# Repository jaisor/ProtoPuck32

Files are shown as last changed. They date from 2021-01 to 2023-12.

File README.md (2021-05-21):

# ProtoPuck32

Multi-purpose prototype box based on ESP32

## Development

USB driver for Windows required: [Silicon Labs CP210X](https://www.silabs.com/developers/usb-to-uart-bridge-vcp-drivers)

Recommended: [VSCode](https://code.visualstudio.com/) + [PlatformIO](https://platformio.org/)

## Issues

LittleFS_esp32 library installed by PlatformIO seems broken, complaining about 

```
error: unknown field 'utime_p' specified in initializer
```
Replacing `libdeps/LittleFS_esp32` with downliad from [LittleFS_esp32](https://www.arduinolibraries.info/libraries/little-fs_esp32) fixes it

## Bill of materials (BOM)

* [ESP32 Wroom](https://www.amazon.com/gp/product/B08D5ZD528)
* [OLED 128x64 i2c](https://www.amazon.com/gp/product/B072Q2X2LL)
* [BME280 Temperature/Humidity sendor i2c](https://www.amazon.com/gp/product/B07KYJNFMD)
* [FPV Camera keypad](https://www.amazon.com/RunCam-Key-Board-FPV-Camera/dp/B0874GPT4W) - I used a joystick style from Caddx, but any would work, case will need adjustment
* [DC plug connector](https://www.amazon.com/gp/product/B01N8VV78D)
* [5V 15A power adapter](https://www.amazon.com/gp/product/B08764XJ2M)
* [White PLA for case and LED diffusion](https://www.amazon.com/gp/product/B01EKEMIIS)

---

## Builds

### LED Node Leaf

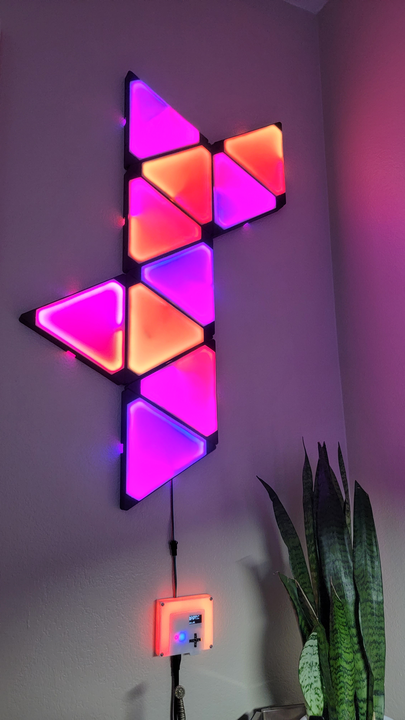
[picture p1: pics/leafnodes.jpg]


Solder the DI/Signal wire (usually middle of the strip) to pin 13, otherwise change the `LED_PIN` in `Configuration.h`

## Bill of materials (BOM)

In addition to the base driver above:
* [WS2812B RGB LED Strip Light](https://www.amazon.com/gp/product/B08B59CBK9/)
* [RGBZONE 20Pairs JST SM 3PIN Plugs](https://www.amazon.com/gp/product/B075K4HLTQ/)

Case - 3D printed, STL files:

* [LED diffuser](case/NodeLeaf/LEDNodeLeafDiffuser.stl)
* [LED frame](case/NodeLeaf/LEDNodeLeafBase.stl)

### LED Matrix

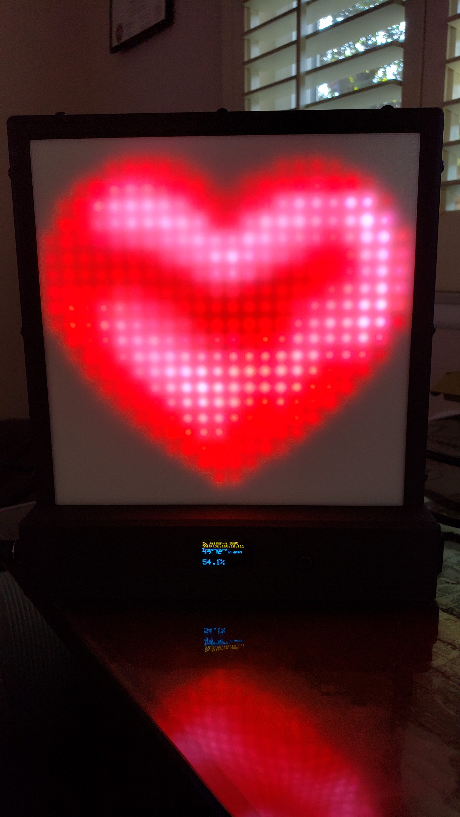
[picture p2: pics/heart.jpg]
LED displaying heart

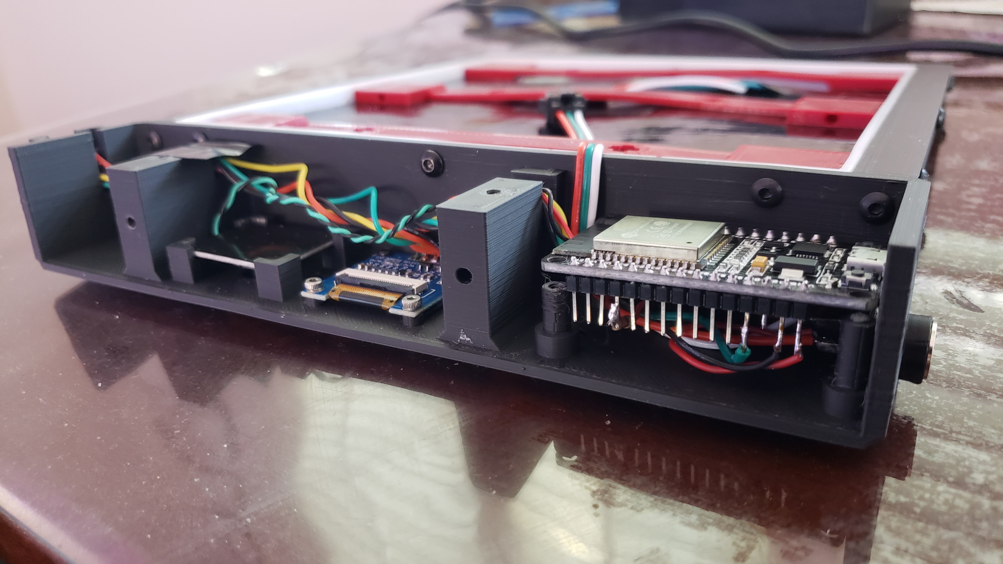
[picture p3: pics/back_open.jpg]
Back-bottom open, shows parts


Add to BOM: [22x22 WS2812B pannel](https://www.amazon.com/gp/product/B075T9RRPM)

Schematic:

Schematic

Case - 3D printed, STL files:

* [LED diffuser](case/LED_Matrix/LEDMatrix-Diffuser.stl)
* [LED frame](case/LED_Matrix/LEDMatrix-FrameSide.stl)
* [LED frame back brace](case/LED_Matrix/LEDMatrix-FrameBackBrace.stl)
* [Base](case/LED_Matrix/LEDMatrix-FrameBase.stl)
* [Base lid](case/LED_Matrix/LEDMatrix-FrameBaseLid.stl)

---

# Bugs / TODO

1. Connecting to Wifi AP after creating one fails - probably something needs to be cleaned up in the WiFi instances
1. Configuration menu
1. Remote controlled pixels via WiFi (HTTP Post or MQTT)
1. Report sensors data and config out to HTTP or MQTT
1. Remote control of config like brightness, mode, etc.
1. Yellow top lines for Config - looks odd
1. Web page headers and titles - remove Demo
1. Get device location automatically if possible
1. Expose current clock broadly, including periodical updates

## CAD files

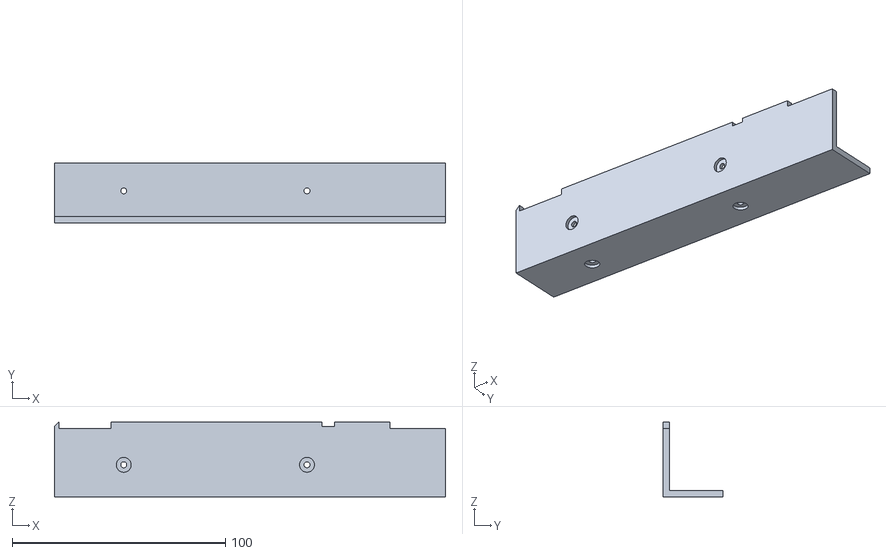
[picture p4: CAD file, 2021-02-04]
case/LED_Matrix/LEDMatrix-FrameBaseLid.stl
183.5 x 28.0 x 35.0

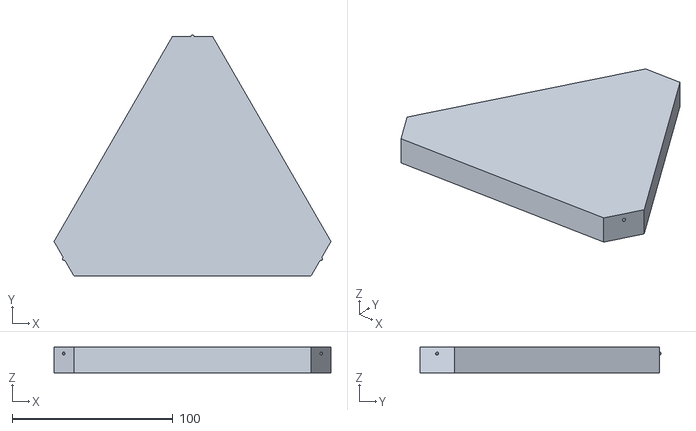
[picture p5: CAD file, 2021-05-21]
case/NodeLeaf/LEDNodeLeafDiffuser.stl
172.5 x 150.3 x 16.0

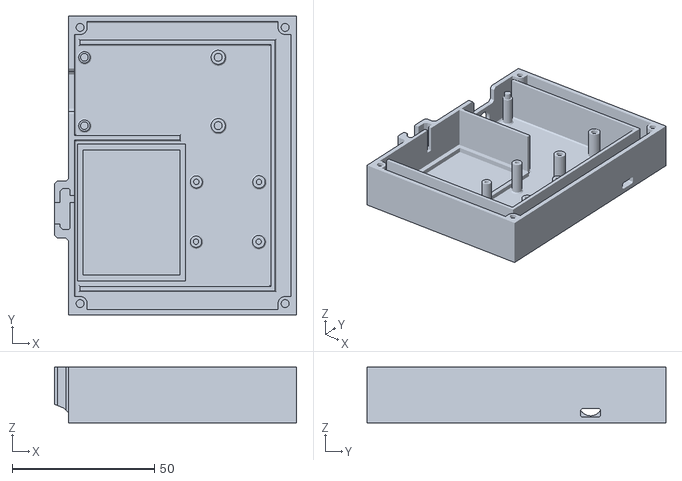
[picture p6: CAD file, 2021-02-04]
case/ProtoPuck32-Case.stl
85.0 x 105.0 x 19.5

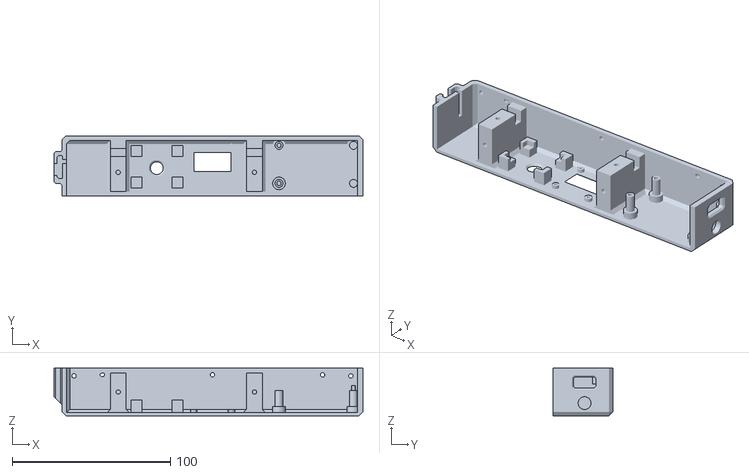
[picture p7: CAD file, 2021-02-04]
case/LED_Matrix/LEDMatrix-FrameBase.stl
195.0 x 38.0 x 30.0

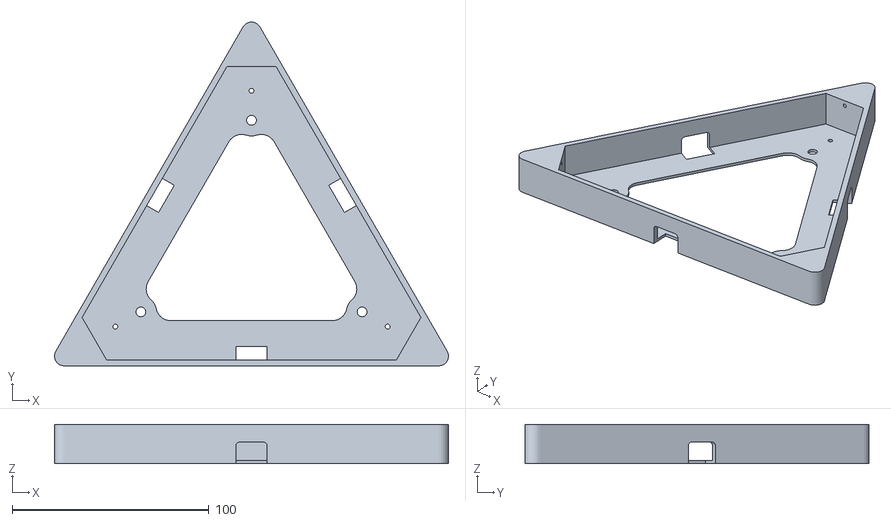
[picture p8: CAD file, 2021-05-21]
case/NodeLeaf/LEDNodeLeafBase.stl
200.5 x 175.0 x 20.0

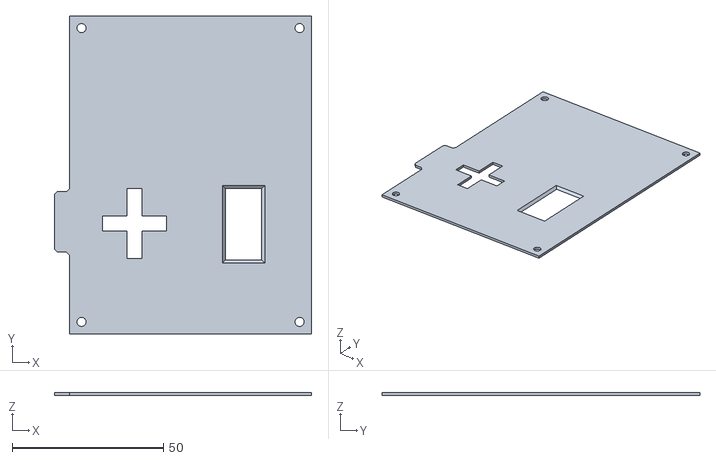
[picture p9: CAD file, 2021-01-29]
case/ProtoPuck32-5ButtonSmall-Lid.stl
85.0 x 105.0 x 1.00

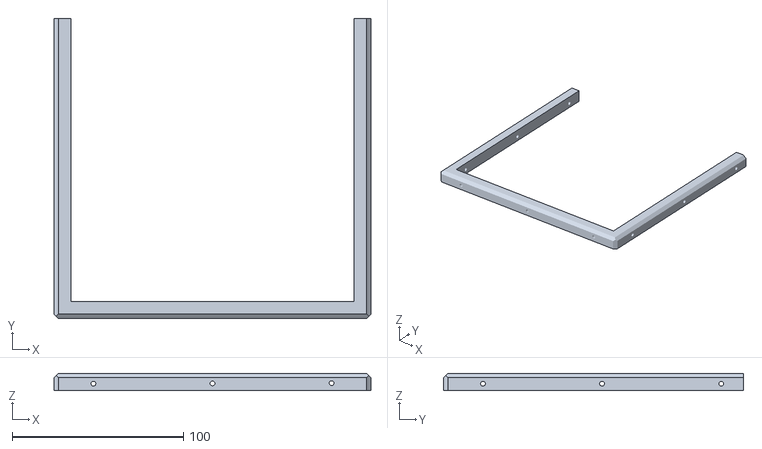
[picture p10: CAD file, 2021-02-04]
case/LED_Matrix/LEDMatrix-FrameSide.stl
185.0 x 175.0 x 10.0

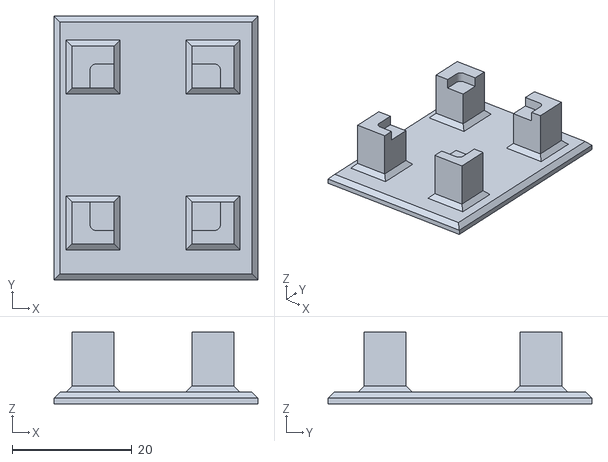
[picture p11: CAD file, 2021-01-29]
case/ProtoPuck32-1Button-Keypad.stl
34.0 x 44.0 x 12.0

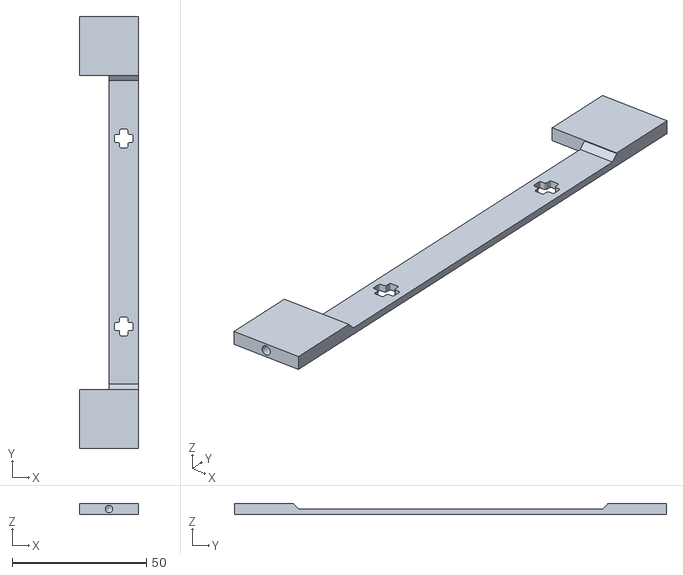
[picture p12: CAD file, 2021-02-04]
case/LED_Matrix/LEDMatrix-FrameBackBrace.stl
22.0 x 161.0 x 4.00

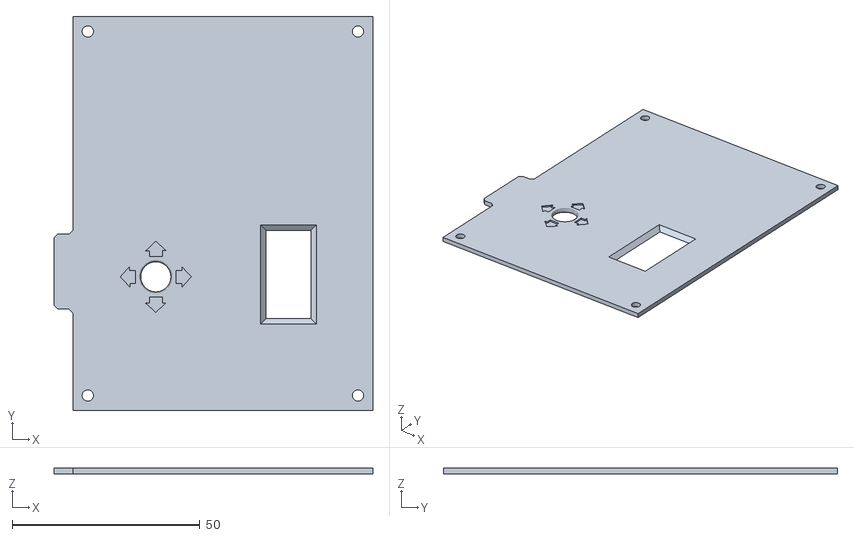
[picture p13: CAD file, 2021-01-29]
case/ProtoPuck32-1Button-Lid.stl
85.0 x 105.0 x 1.50

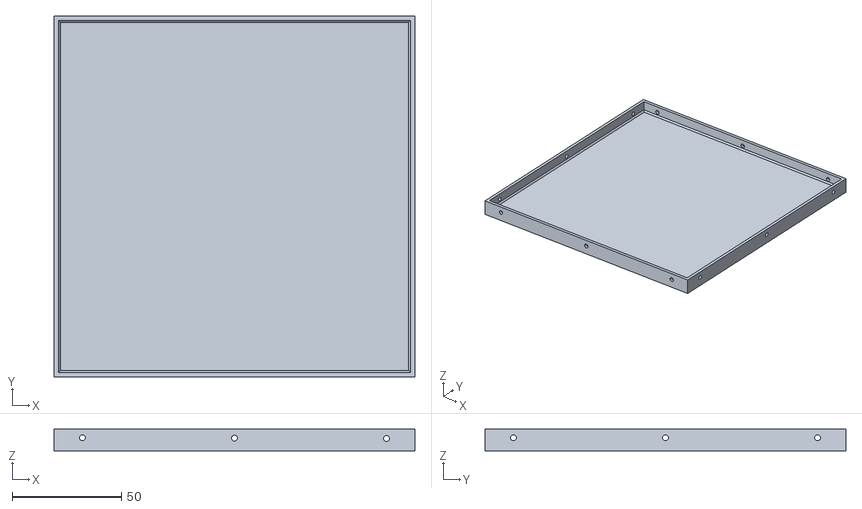
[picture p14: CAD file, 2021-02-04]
case/LED_Matrix/LEDMatrix-Diffuser.stl
165.0 x 165.0 x 10.0

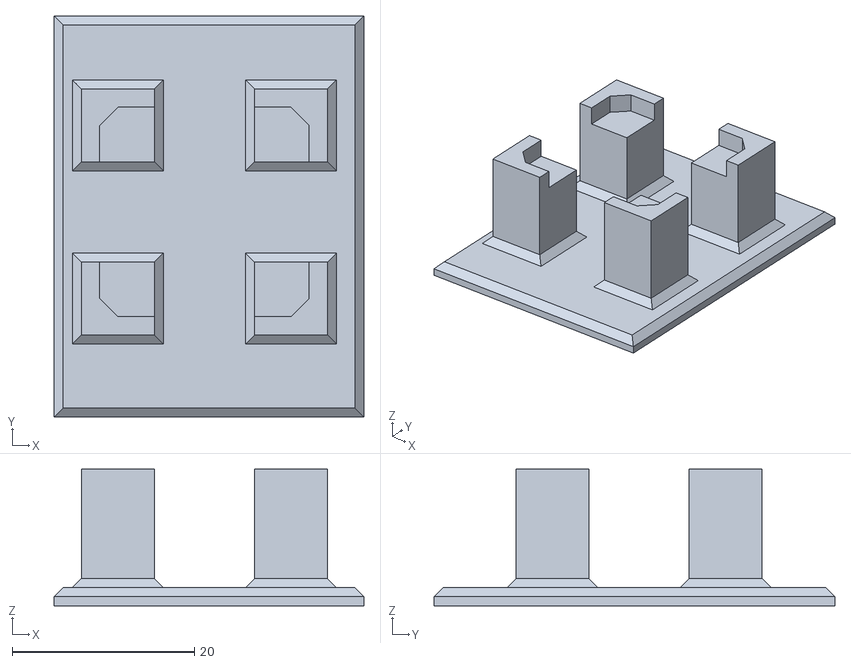
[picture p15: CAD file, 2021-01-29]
case/ProtoPuck32-5Button-Lid.stl
34.0 x 44.0 x 15.0

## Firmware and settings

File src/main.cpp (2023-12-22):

#include <Arduino.h>

#include <functional>

#if !( defined(ESP32) )
  #error This code is intended to run on ESP32 platform! Please check your Tools->Board setting.
#endif


#include "Configuration.h"
#include "Device.h"
#include "StateController.h"

CDevice *device;
CStateController *stateController;

unsigned long tsSmoothBoot;
bool smoothBoot;

float p = 0;

void setup() {
  delay( 100 ); // power-up safety delay

  Serial.begin(115200);  while (!Serial); delay(200);
  randomSeed(analogRead(0));

  Log.begin(LOG_LEVEL_NOTICE, &Serial);
  Log.noticeln("Initializing...");  

  if (EEPROM_initAndCheckFactoryReset() >= 3) {
    log_w("Factory reset conditions met!");
    EEPROM_wipe();    
  }

  tsSmoothBoot = millis();
  smoothBoot = false;

  EEPROM_loadConfig();

  //strcpy(configuration.wifiSsid, "<REDACTED>");
  //strcpy(configuration.wifiPassword, "<REDACTED>");
  //EEPROM_saveConfig();

  device = new CDevice();
  stateController = new CStateController(device);
}

void loop() {

  if (!smoothBoot && millis() - tsSmoothBoot > FACTORY_RESET_CLEAR_TIMER_MS) {
    smoothBoot = true;
    EEPROM_clearFactoryReset();
    log_v("Device booted smoothly!");
  }

  stateController->loop();
  device->loop();
}

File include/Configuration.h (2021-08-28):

#ifndef _CONFIGURATION_H
#define _CONFIGURATION_H

#include <Arduino.h>

#define WIFI        // 2.4Ghz wifi access point
#define LED         // Individually addressible LED strip
#define OLED        // Display
#define TEMP_SENSOR // Temperature, humidity, pressure
#define KEYPAD      // Buttons

#define ALEX_GIFT   // Temp, since the keyboard is flipped. TODO: implement key mapping sequence.

#define BOOT_BUTTON 0
#define EEPROM_CONFIGURATION_START 0    // First EEPROM byte to be used for storing the configuration

#ifdef WIFI
    #define WIFI_SSID "ProtoPuck32"
    #define WIFI_PASS "password123"

    // If unable to connect, it will create a soft accesspoint
    #define WIFI_FALLBACK_SSID "PP" // device chip id will be suffixed
    #define WIFI_FALLBACK_PASS "password123"

    #define NTP_SERVER "pool.ntp.org"
    #define NTP_GMT_OFFSET_SEC -25200
    #define NTP_DAYLIGHT_OFFSET_SEC 0

    // Web server
    #define WEB_SERVER_PORT 80
#endif

#ifdef LED
    #define LED_PIN 13
    #define LED_STRIP_SIZE 31
    #define LED_BRIGHTNESS 0.5 // 0-1
    #define LED_TYPE WS2811
    #define LED_COLOR_ORDER GRB

    #define LED_EXTERNAL    
    #ifdef LED_EXTERNAL
        #define LED_EXTERNAL_PIN 12
        #define LED_EXTERNAL_STRIP_SIZE 700 // 70 PER LEAF // 28
        #define LED_EXTERNAL_BRIGHTNESS 0.2 // 0-1
        #define LED_EXTERNAL_TYPE WS2812B
        #define LED_EXTERNAL_COLOR_ORDER GRB

        #define LED_EXTERNAL_MATRIX
        #ifdef LED_EXTERNAL_MATRIX
            #define LED_EXTERNAL_MATRIX_WIDTH 22
            #define LED_EXTERNAL_MATRIX_HEIGHT 22
            #define LED_EXTERNAL_MATRIX_SERPENTINE true
            #define LED_EXTERNAL_MATRIX_VERTICAL false
        #endif

        //#define LED_EXTERNAL_LEAFS
        #ifdef LED_EXTERNAL_LEAFS
            #define LED_EXTERNAL_LEAF_SIZE 70
        #endif
    #endif

#endif

#ifdef OLED
    #define OLED_SCREEN_WIDTH 128 // OLED display width, in pixels
    #define OLED_SCREEN_HEIGHT 64 // OLED display height, in pixel
    #define OLED_I2C_ID  0x3C
#endif

#ifdef KEYPAD
    #define KEYPAD_PIN 34
#endif

#ifdef TEMP_SENSOR
    #define BME_I2C_ID  0x76
#endif

struct configuration_t {

    bool _loaded; // used to check if EEPROM was empty, should be true

    #ifdef WIFI
        char wifiSsid[32];
        char wifiPassword[63];
        char ntpServer[128];
        long gmtOffset_sec = 0;
        int daylightOffset_sec = 3600;
    #endif

    #ifdef LED
        float ledBrightness;
    #endif
};

extern configuration_t configuration;

void EEPROM_saveConfig();
void EEPROM_loadConfig();
void EEPROM_wipe();

#endif

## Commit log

2021-01-17 Moved config to dedicated header file
    [Configuration.h]
2021-01-18 basic wifi ability to join or create AP
    [Configuration.h]
2021-01-19 very basic web request POC
    [Configuration.h]
2021-01-19 more progress and added LED animation from example
    [Configuration.h]
2021-01-23 Two LED strips. Keyboard sensing. More foundation. Wifi connect web form.
    [Configuration.h]
2021-01-23 strip specific brightness
    [Configuration.h]
2021-01-25 working keypad, including manager listers, some cosmetic tweaks
    [Configuration.h]
2021-01-25 left/right buttons change external demo stripe palette
2021-01-27 refactor to allow partial compile, keyboard work and tweaks, started on MQTT impl
    [Configuration.h]
2021-01-27 working led matrix foundation
    [Configuration.h]
2021-01-29 Wifi default to AP works, small tweaks
    [Configuration.h]
2021-01-29 added case 3D printable STL
    [ProtoPuck32-1Button-Keypad.stl, ProtoPuck32-1Button-Lid.stl, ProtoPuck32-5Button-Lid.stl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]
2021-01-30 ESP native log, fixed config EEPROM to actually work
    [Configuration.h]
2021-01-30 Config cleanup and web wifi bug fix
    [WifiManager.cpp]
2021-02-02 Alex flipped keyboard
    [Configuration.h]
2021-02-04 keyboard filter and picture modes for led matrix work well
    [ProtoPuck32-Case.stl]
2021-02-04 Case for LED matrix design
    [Configuration.h, LEDMatrix-Diffuser.stl, LEDMatrix-FrameBackBrace.stl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]
2021-02-06 Readme, schematics, pics, stl and started on IoT control
2021-02-06 rest of case parts listed in Readme
2021-02-08 game of life implemented
    [Configuration.h]
2021-02-12 key config
    [Configuration.h]
2021-02-13 works but needs cleanup, and WIP
    [Configuration.h]
2021-02-14 State and Device refactor code complete
2021-02-20 More work on config system
    [Configuration.h]
2021-02-24 fixed schematic to take 3.3v ok keypad voltage divider
2021-02-25 falling stars
    [Configuration.h]
2021-03-01 keypad tweak and fix error in schematic
    [Device.cpp]
2021-03-10 started on clock and basic NTP
    [Configuration.h]
2021-03-24 clock works, progress on fireworks
    [Configuration.h]
2021-05-16 Patched non-matrix mode
    [Configuration.h]
2021-05-17 working led leafs
    [Configuration.h]
2021-05-21 NodeLeaf build
    [Configuration.h, LEDNodeLeafBase.stl, LEDNodeLeafDiffuser.stl]
2021-05-30 screen dims at night
    [Configuration.h]
2021-09-04 work on sound level mode
    [Configuration.h]
2021-09-18 clear leds on startup
2022-03-11 config resiliance
    [Configuration.h]
2022-08-07 Updated configuration imp
    [Configuration.h]
2022-08-18 broken audio
    [Configuration.h]
2022-08-18 pedantic gcc fixes
    [Configuration.h]
2022-08-18 rollback esp32 platform to fix i2c mic
    [Configuration.h]
2022-09-10 MQTT as JSON and some other improvements
    [Configuration.h]
2023-11-12 Updated AndroidJson lib, and added npt config to web ui
    [Configuration.h]
2023-12-22 Configs templates for different devices and few small tweaks
